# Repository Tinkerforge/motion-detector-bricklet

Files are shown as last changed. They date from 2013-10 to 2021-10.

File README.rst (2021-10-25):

Motion Detector Bricklet
========================

This repository contains the firmware source code and the hardware design
files. The documentation generator configs can be found at
https://github.com/Tinkerforge/generators

Repository Content
------------------

software/:
 * examples/: Examples for all supported languages
 * build/: Compiled files
 * src/: Source code of firmware
 * Makefile: Makefile to build project

hardware/:
 * Contains KiCad project files and additionally schematics as PDF

datasheets/:
 * Contains datasheets for sensors and complex ICs that are used

Hardware
--------

The hardware is designed with the open source EDA Suite KiCad
(http://www.kicad.org). Before you are able to open the files,
you have to install the Tinkerforge kicad-libraries
(https://github.com/Tinkerforge/kicad-libraries). You can either clone
them directly in hardware/ or clone them in a separate folder and
symlink them into hardware/
(ln -s kicad_path/kicad-libraries project_path/hardware). After that you
can open the .pro file in hardware/ with KiCad and from there view and
modify the schematics and the PCB layout.

Software
--------

If you want to do your own Brick/Bricklet firmware development we highly
recommend that you use our build environment setup script and read the
tutorial (https://www.tinkerforge.com/en/doc/Tutorials/Tutorial_Build_Environment/Tutorial.html).

To compile the C code we recommend you to install the newest GNU Arm Embedded
Toolchain (https://launchpad.net/gcc-arm-embedded/+download).
You also need to install bricklib (https://github.com/Tinkerforge/bricklib)
and brickletlib (https://github.com/Tinkerforge/brickletlib).

You can either clone it directly in software/src/ or clone it in a
separate folder and symlink it into software/src/
(ln -s bricklib_path/bricklib project_path/software/src/ and
ln -s brickletlib_path/brickletlib project_path/software/src/).
Finally make sure to have CMake installed
(http://www.cmake.org/cmake/resources/software.html).

After that you can build the firmware by invoking make in software/.
The firmware (.bin) can then be found in software/build/ and uploaded
with brickv (click button "Flashing" on start screen).

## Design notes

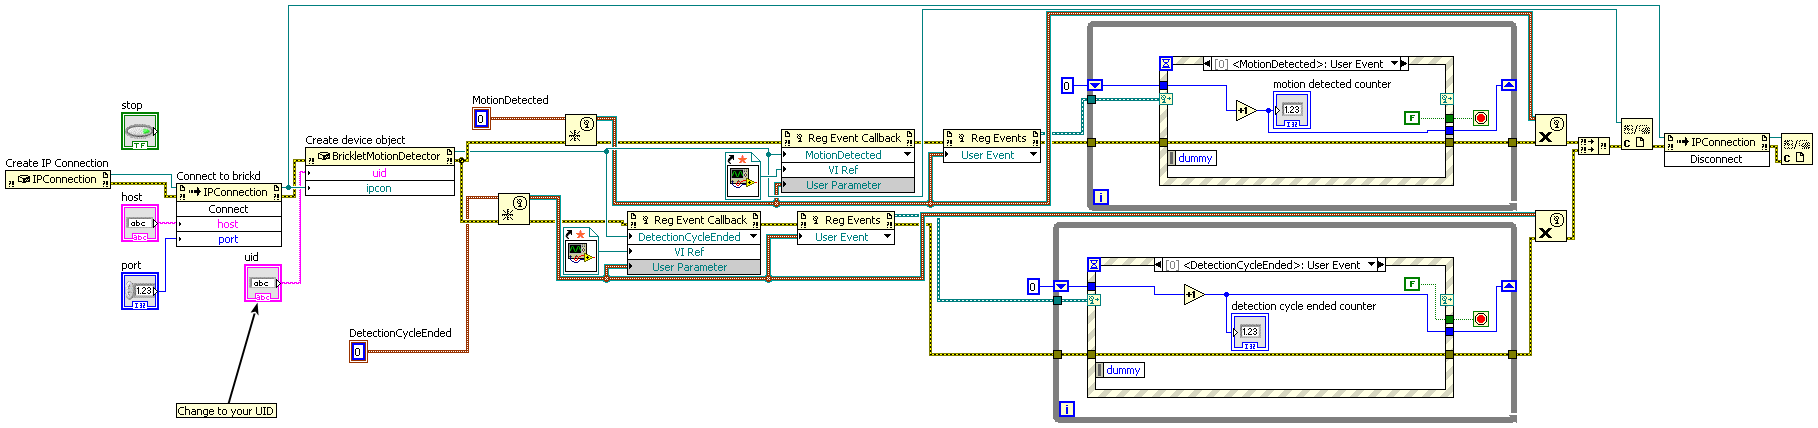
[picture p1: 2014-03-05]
software/examples/labview/Example Callback.vi.png

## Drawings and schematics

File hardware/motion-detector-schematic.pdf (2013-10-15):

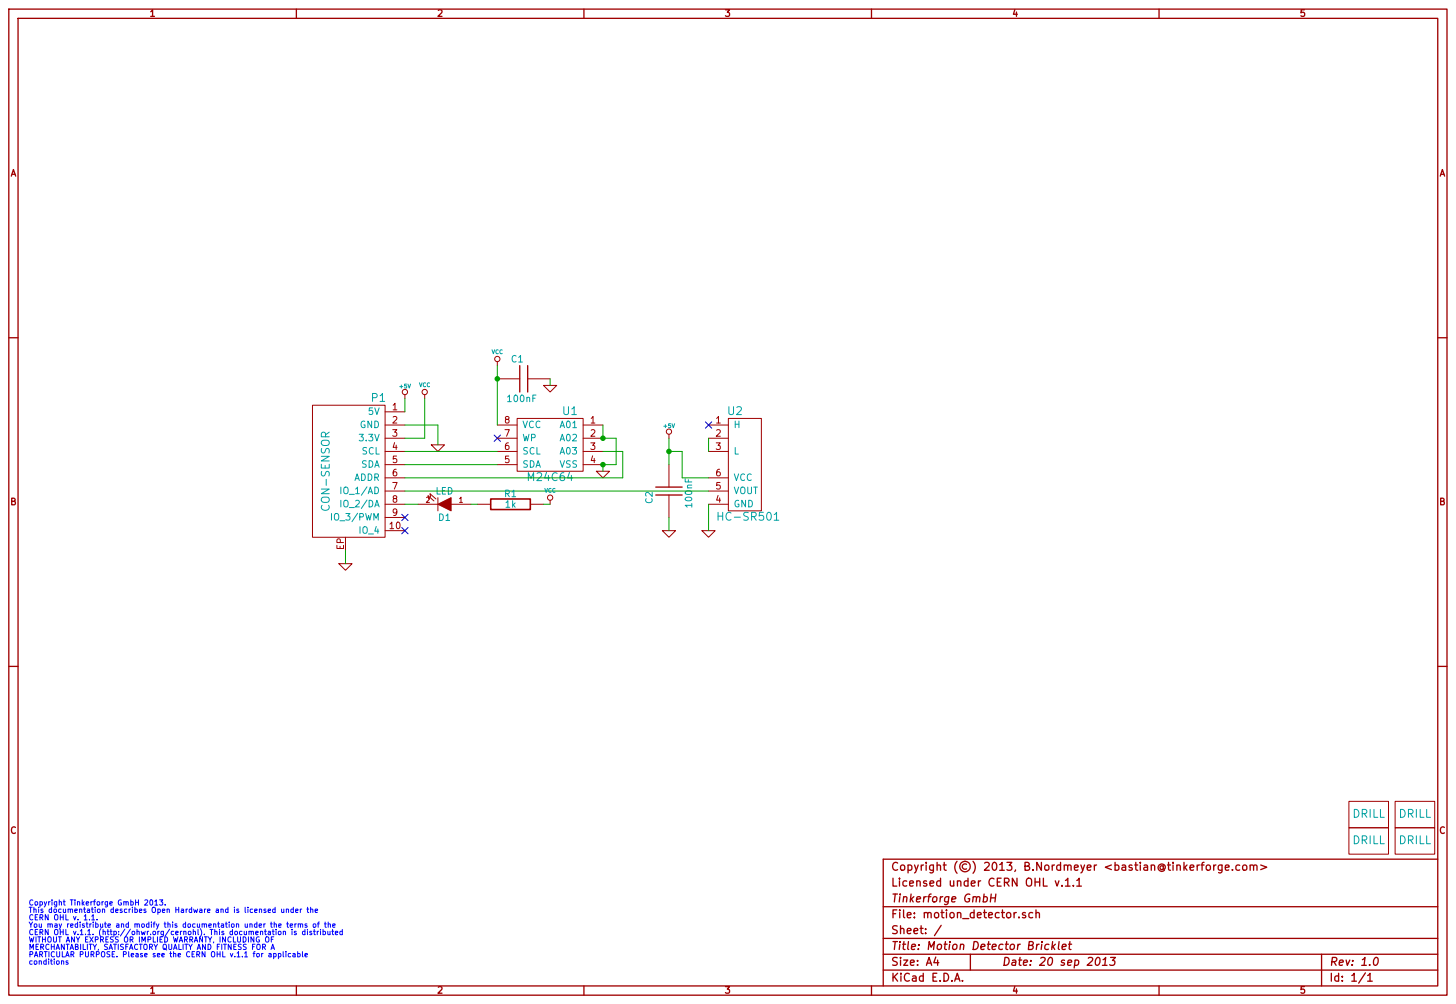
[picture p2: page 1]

VCC Copyright Tinkerforge GmbH 2013. This documentation describes Open Hardware and is licensed under the CERN OHL v. 1.1. You may redistribute and modify this documentation under the terms of the CERN OHL v.1.1. (http://ohwr.org/cernohl). This documentation is distributed WITHOUT ANY EXPRESS OR IMPLIED WARRANTY, INCLUDING OF MERCHANTABILITY, SATISFACTORY QUALITY AND FITNESS FOR A

Copyright (©) 2013, B.Nordmeyer <bastian@tinkerforge.com>
Licensed under CERN OHL v.1.1
Tinkerforge GmbH
Id: 1/1 Title: Motion Detector Bricklet File: motion_detector.sch
Sheet: /

PARTICULAR PURPOSE. Please see the CERN OHL v.1.1 for applicable

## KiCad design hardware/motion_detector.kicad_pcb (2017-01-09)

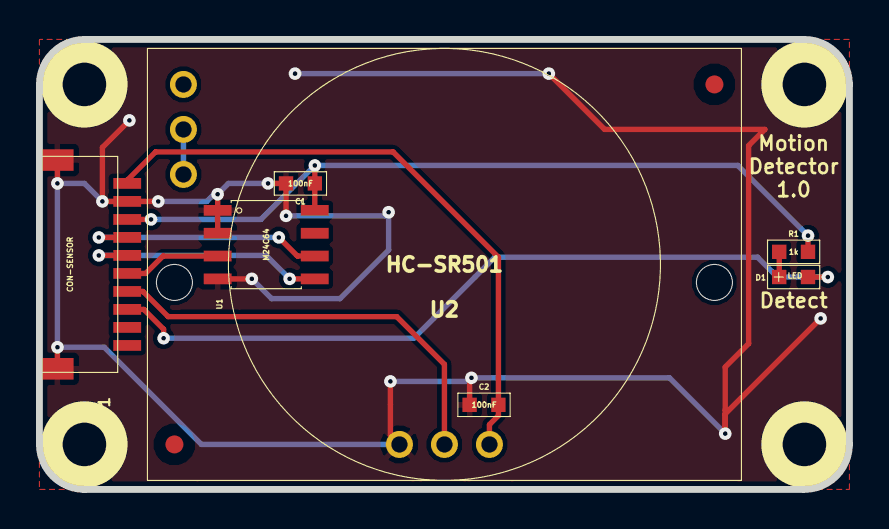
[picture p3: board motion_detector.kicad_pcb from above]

Board: 2 copper layers, 45.0 x 25.0 mm, 15 parts (0 on the bottom side), 10 nets.

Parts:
C1, C2: 100nF; 0603
D1: LED; D0603
Fiducial_Mark: VAL**; Fiducial_Mark
Fiducial_Mark#2: VAL**; Fiducial_Mark
P1: CON-SENSOR
R1: 1k; 0603
U1: M24C64; SOIC8
U2: HC-SR501
U3, U4, U5, U6: DRILL; DRILL_NP
VAL: WEEE_7mm
VAL#2: CE_5mm

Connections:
+5V: C2.2, P1.1, U2.6
GND: C1.2, C2.1, P1.2, P1.EP, U1.1, U1.2, U1.4, U2.4
unnamed: P1.7, U2.5
unnamed: U2.2, U2.3
unnamed: P1.6, U1.3
unnamed: D1.2, P1.8
unnamed: D1.1, R1.1
unnamed: P1.4, U1.6
unnamed: P1.5, U1.5
VCC: C1.1, P1.3, R1.2, U1.8

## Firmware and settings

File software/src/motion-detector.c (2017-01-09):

/* motion-detector-bricklet
 * Copyright (C) 2013 Olaf Lüke <olaf@tinkerforge.com>
 *
 * motion-detector.c: Implementation of Motion Detector Bricklet messages
 *
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
 * You should have received a copy of the GNU Lesser General Public
 * License along with this library; if not, write to the
 * Free Software Foundation, Inc., 59 Temple Place - Suite 330,
 * Boston, MA 02111-1307, USA.
 */

#include "motion-detector.h"

#include "bricklib/bricklet/bricklet_communication.h"
#include "bricklib/utility/util_definitions.h"
#include "bricklib/utility/init.h"
#include "brickletlib/bricklet_entry.h"
#include "brickletlib/bricklet_debug.h"
#include "config.h"

void invocation(const ComType com, const uint8_t *data) {
	switch(((MessageHeader*)data)->fid) {
		case FID_GET_MOTION_DETECTED: {
			get_motion_detected(com, (GetMotionDetected*)data);
			return;
		}

		case FID_SET_STATUS_LED_CONFIG: {
			set_status_led_config(com, (SetStatusLEDConfig*)data);
			return;
		}

		case FID_GET_STATUS_LED_CONFIG: {
			get_status_led_config(com, (GetStatusLEDConfig*)data);
			return;
		}

		default: {
			BA->com_return_error(data, sizeof(MessageHeader), MESSAGE_ERROR_CODE_NOT_SUPPORTED, com);
			return;
		}
	}
}

void get_motion_detected(const ComType com, const GetMotionDetected *data) {
	GetMotionDetectedReturn gmdr;
	gmdr.header        = data->header;
	gmdr.header.length = sizeof(GetMotionDetectedReturn);
	gmdr.motion        = BC->motion;

	BA->send_blocking_with_timeout(&gmdr, sizeof(GetMotionDetectedReturn), com);
	logbli("get_motion_detected: %d\n\r", BC->motion);
}

void set_status_led_config(const ComType com, const SetStatusLEDConfig *data) {
	if(data->led_config > STATUS_LED_CONFIG_STATUS) {
		BA->com_return_error(data, sizeof(MessageHeader), MESSAGE_ERROR_CODE_INVALID_PARAMETER, com);
		return;
	}

	BC->status_led_config = data->led_config;

	if((BC->status_led_config == STATUS_LED_CONFIG_OFF) || (BC->status_led_config == STATUS_LED_CONFIG_STATUS && BC->motion == MOTION_NOT_DETECTED)) {
		PIN_LED.pio->PIO_SODR = PIN_LED.mask;
	} else {
		PIN_LED.pio->PIO_CODR = PIN_LED.mask;
	}
}

void get_status_led_config(const ComType com, const GetStatusLEDConfig *data) {
	GetStatusLEDConfigReturn gslcr;
	gslcr.header        = data->header;
	gslcr.header.length = sizeof(GetStatusLEDConfigReturn);
	gslcr.led_config    = BC->status_led_config;

	BA->send_blocking_with_timeout(&gslcr, sizeof(GetStatusLEDConfigReturn), com);
}

void constructor(void) {
	_Static_assert(sizeof(BrickContext) <= BRICKLET_CONTEXT_MAX_SIZE, "BrickContext too big");

	BC->motion = MOTION_NOT_DETECTED;
	BC->motion_detected = false;
	BC->detection_cycle_ended = false;
	BC->debounce = 0;
	BC->status_led_config = STATUS_LED_CONFIG_STATUS;

    PIN_DETECT.type = PIO_INPUT;
    PIN_DETECT.attribute = PIO_DEFAULT;
    BA->PIO_Configure(&PIN_DETECT, 1);

    PIN_LED.type = PIO_OUTPUT_1;
    PIN_LED.attribute = PIO_DEFAULT;
    BA->PIO_Configure(&PIN_LED, 1);
}

void destructor(void) {
    PIN_DETECT.type = PIO_INPUT;
    PIN_DETECT.attribute = PIO_PULLUP;
    BA->PIO_Configure(&PIN_DETECT, 1);
}

void tick(const uint8_t tick_type) {
	if(tick_type & TICK_TASK_TYPE_CALCULATION) {
		if(BC->debounce > 0) {
			BC->debounce--;
			return;
		}

		if(PIN_DETECT.pio->PIO_PDSR & PIN_DETECT.mask) {
			if(BC->motion != MOTION_DETECTED) {
				BC->motion = MOTION_DETECTED;
				BC->debounce = MOTION_DEBOUNCE;
				BC->motion_detected = true;

				if(BC->status_led_config == STATUS_LED_CONFIG_STATUS) {
					PIN_LED.pio->PIO_CODR = PIN_LED.mask;
				}
			}
		} else {
			if(BC->motion != MOTION_NOT_DETECTED) {
				BC->motion = MOTION_NOT_DETECTED;
				BC->debounce = MOTION_DEBOUNCE;
				BC->detection_cycle_ended = true;

				if(BC->status_led_config == STATUS_LED_CONFIG_STATUS) {
					PIN_LED.pio->PIO_SODR = PIN_LED.mask;
				}
			}
		}
	}

	if(tick_type & TICK_TASK_TYPE_MESSAGE) {
		if(BC->motion_detected) {
			MotionDetected md;
			BA->com_make_default_header(&md, BS->uid, sizeof(MotionDetected), FID_MOTION_DETECTED);
			BA->send_blocking_with_timeout(&md,
										   sizeof(MotionDetected),
										   *BA->com_current);

			BC->motion_detected = false;
			logbli("MotionDetected\n\r");
		}

		if(BC->detection_cycle_ended) {
			DetectionCycleEnded dce;
			BA->com_make_default_header(&dce, BS->uid, sizeof(DetectionCycleEnded), FID_DETECTION_CYCLE_ENDED);
			BA->send_blocking_with_timeout(&dce,
										   sizeof(DetectionCycleEnded),
										   *BA->com_current);

			BC->detection_cycle_ended = false;
			logbli("DetectionCycleEnded\n\r");
		}
	}
}

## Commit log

2013-07-31 Add prototype disclaimer to readme
2013-09-24 Control LED according to detection cycle
2013-10-15 add hardware files
    [motion_detector.kicad_pcb]
2013-10-18 Use correct file as schematic
2014-04-02 perl: Unify print style
2014-12-04 remove big silkscreen lines
    [motion_detector.kicad_pcb]
2014-12-15 fix text position
    [motion_detector.kicad_pcb]
2015-08-07 Use full device class name in Python examples
2016-05-18 c: Add missing device destroy call
2016-08-04 fix plane outlines
    [motion_detector.kicad_pcb]
2016-08-09 fix pcb name
    [motion_detector.kicad_pcb]
2017-01-09 Add status LED configuration support
2018-02-20 Cleanup KiCad libraries config
    Ensure LibDir=kicad-libraries and LibName1=tinkerforge.
    Remove special library.
2018-02-26 Add missing schematic
    [motion_detector.sch]
2021-10-25 Update KiCad link
    https://www.kicad.org/blog/2021/10/Avoid-links-to-former-kicad-domain/
